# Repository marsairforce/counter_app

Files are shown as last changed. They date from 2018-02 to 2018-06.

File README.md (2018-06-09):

# A simple counter application

This is a device that has 2 7-segment displays, and buttons.
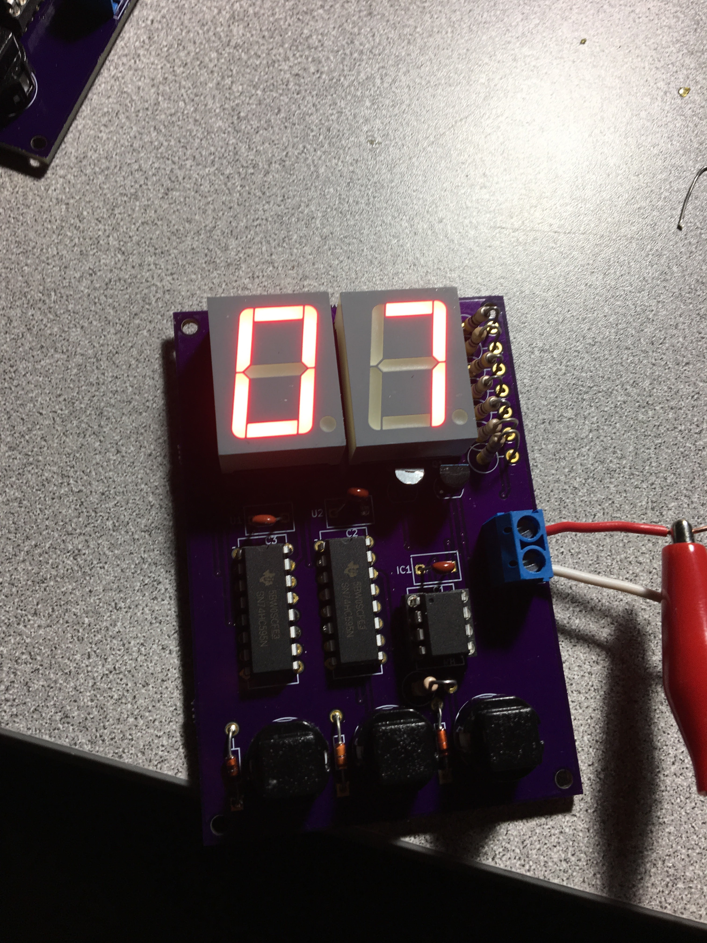
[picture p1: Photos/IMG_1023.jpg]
Counter Application


It can be used for simple manual counting of something.
I originally built it for a "It has been xx days since.." signs.

But it can also be used for one of those "Now serving xx" signs.

This project was a test of the waters to see what OSHPark is able to create.

It started off as a breadboard experiment, then a hand wire job on a punchboard, and then a finished PCB board.

It was an exercise to learn how to use Kicad as well. Before I had been trying to use gEDA and suite to make a circuit board layout, but never got past the schematic phase. Perhaps because there is no existing parts or footprint library for gEDA and also no documentation for how to use the tools (that are not even GUI based) to try to create a symbol and a footprint.  I was able to get farther with Kicad in an evening than I was able to get over several years of coming back to poking at gEDA.

It was also the first product built using Attiny-85 device. Learning how to use shift registers, multiplex switch button inputs, software interrupts.

All the components were things I had in stock, thru-hole parts.

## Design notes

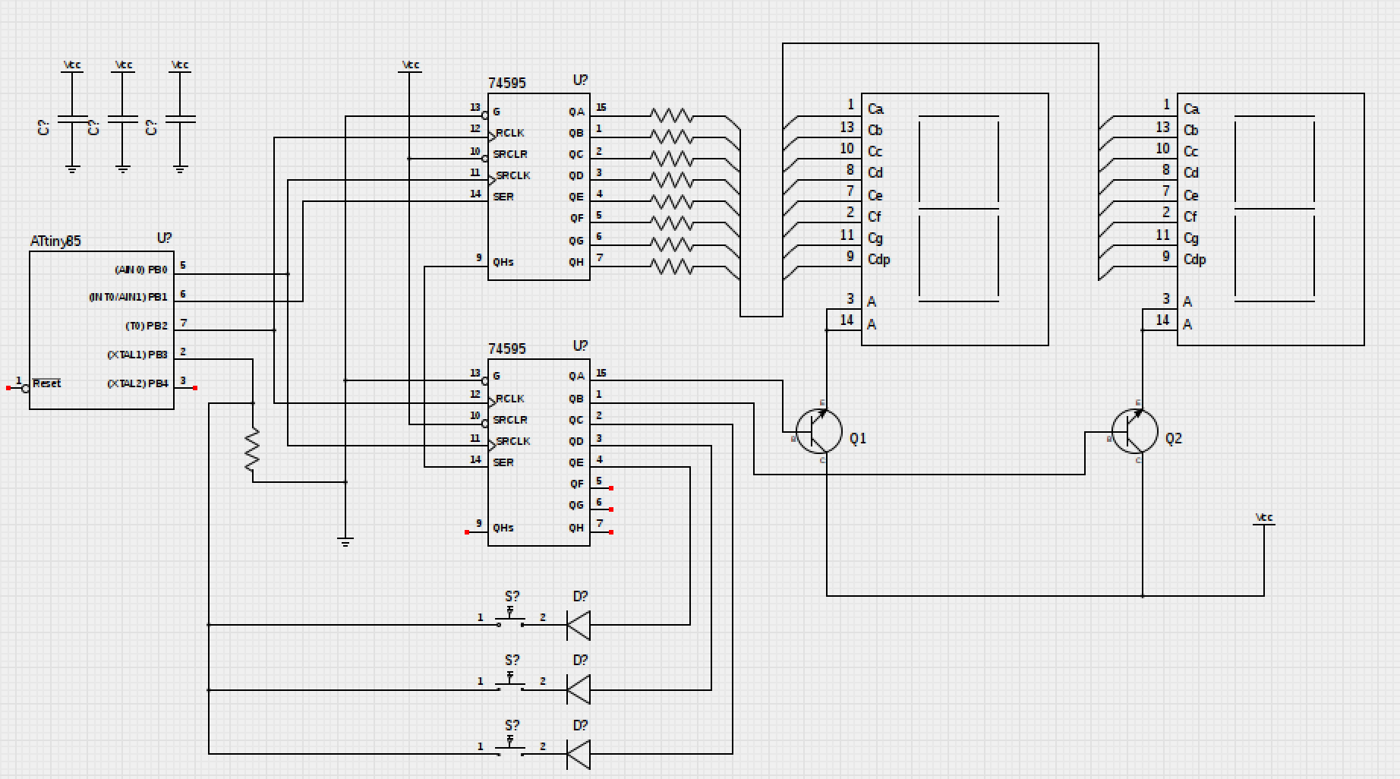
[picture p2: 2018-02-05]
Photos/Screen Shot 2017-01-28 at 11.42.11 PM.png

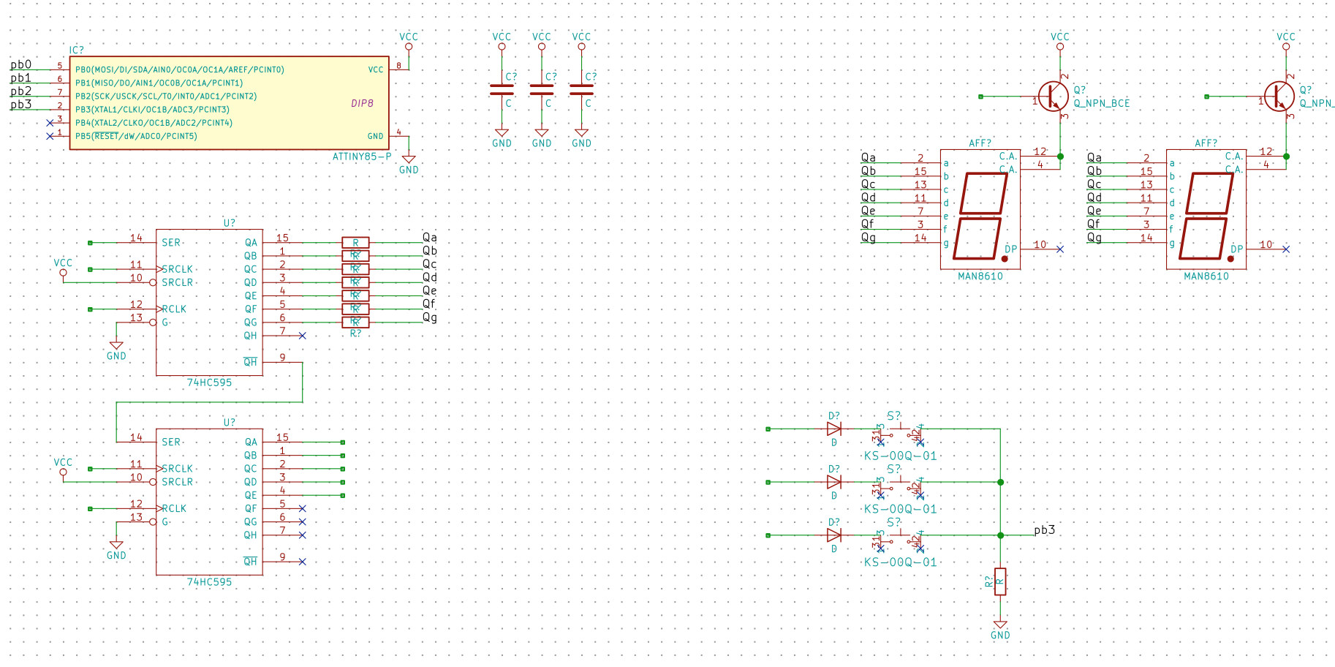
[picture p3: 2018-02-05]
Photos/Screen Shot 2017-01-30 at 12.58.02 AM.png

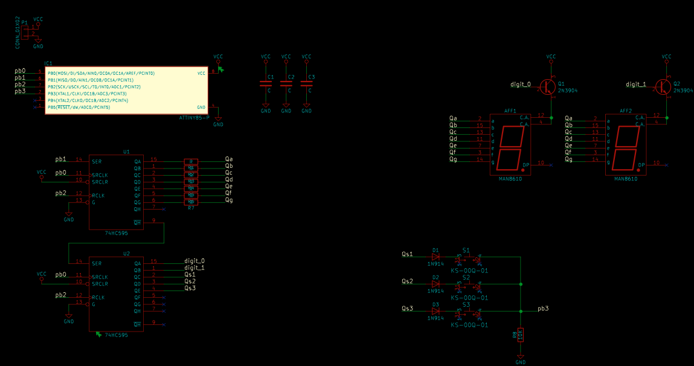
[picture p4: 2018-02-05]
Photos/Screen Shot 2017-02-01 at 12.23.13 AM.png

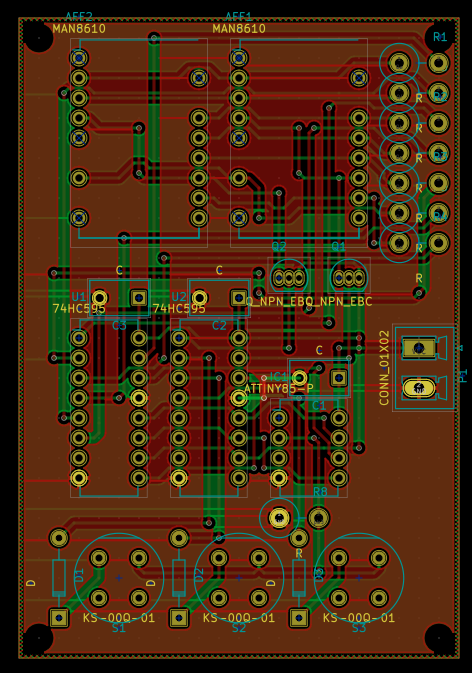
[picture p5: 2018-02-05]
Photos/Screen Shot 2017-02-01 at 12.17.23 AM.png

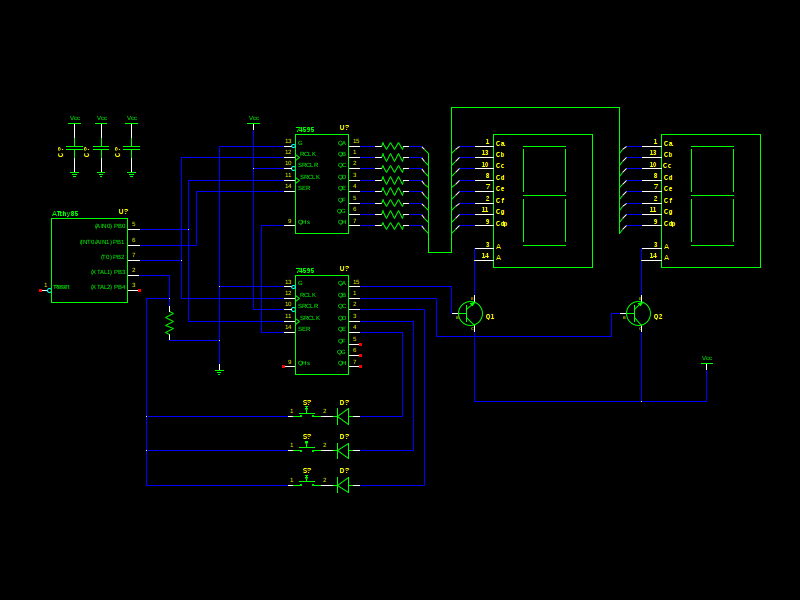
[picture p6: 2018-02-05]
sketch_jan25a.png

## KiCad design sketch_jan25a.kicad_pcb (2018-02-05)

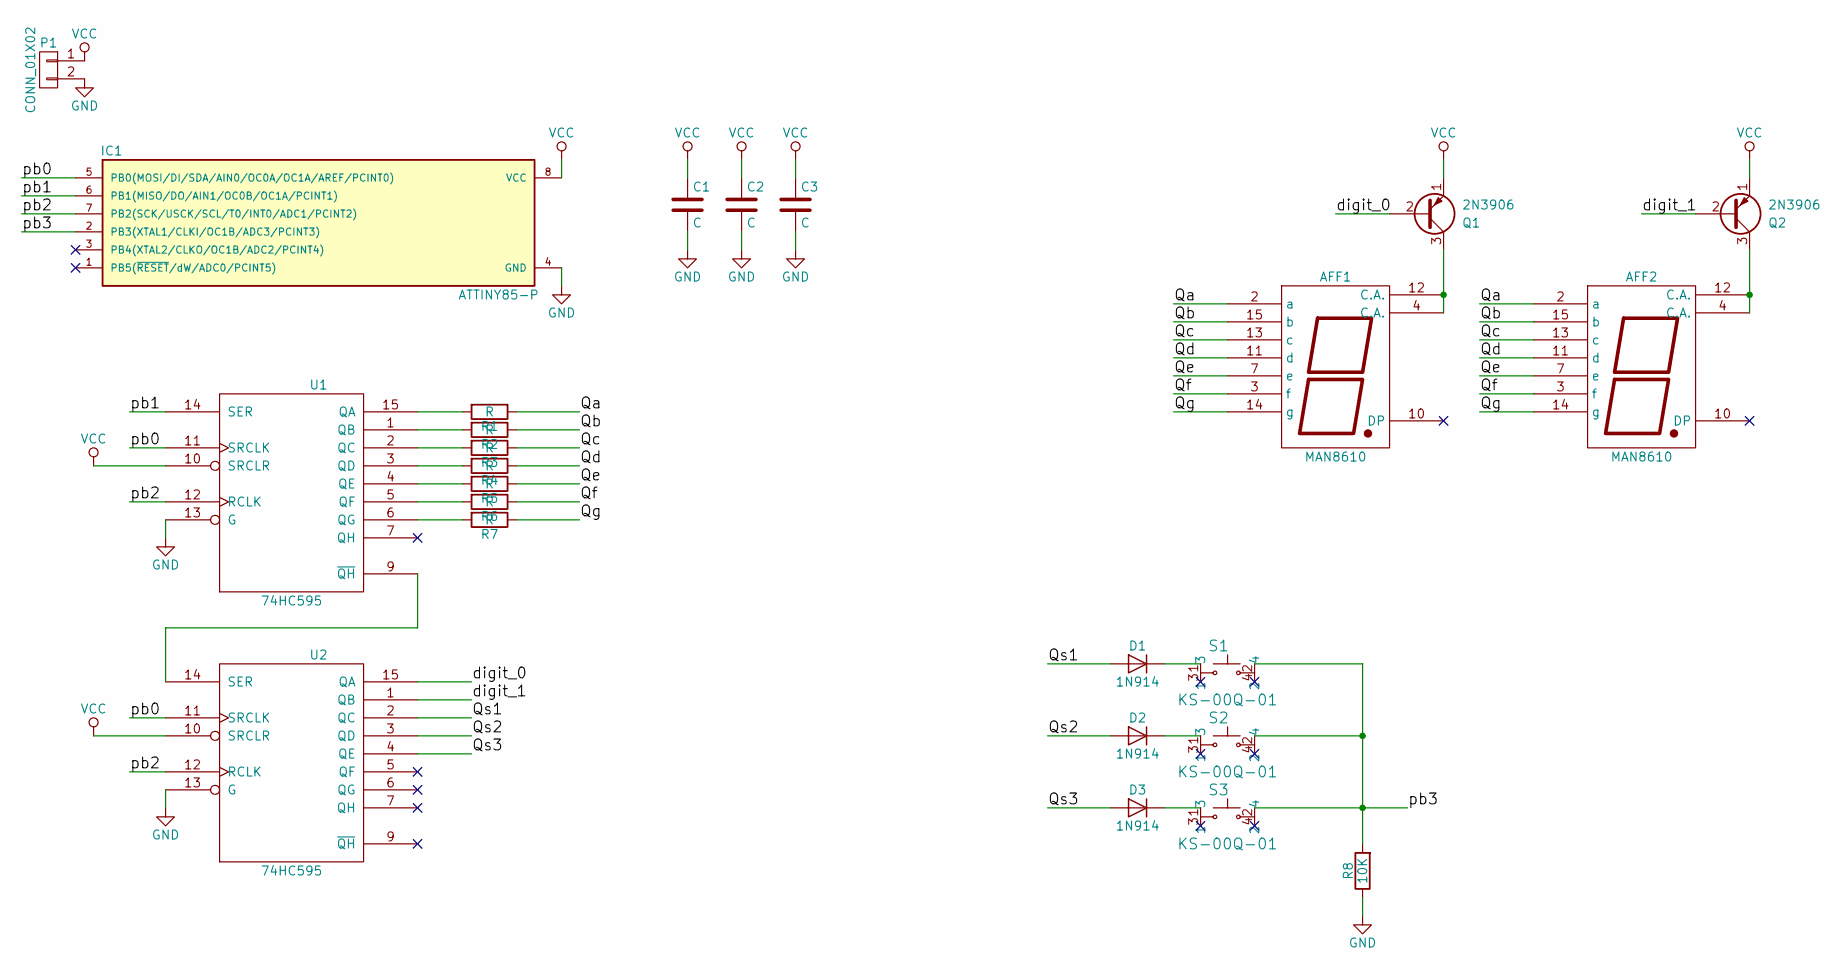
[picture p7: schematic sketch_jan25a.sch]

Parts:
AFF1, AFF2: MAN8610
C1, C2, C3: C; C_Rect_L7_W2.5_P5
D1, D2, D3: 1N914; Diode_DO-35_SOD27_Horizontal_RM10
IC1: ATTINY85-P; DIP-8_W7.62mm
P1: CONN_01X02
Q1, Q2: 2N3906; TO-92_Inline_Narrow_Oval
R1, R2, R3, R4, R5, R6, R7: R; Resistor_Vertical_RM5mm
R8: 10K; Resistor_Vertical_RM5mm
S1, S2, S3: KS-00Q-01; e_switch
U1, U2: 74HC595; DIP-16_W7.62mm

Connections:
/Qa: AFF1.2 (a), AFF2.2 (a), R1.1
/Qb: AFF1.15 (b), AFF2.15 (b), R2.1
/Qc: AFF1.13 (c), AFF2.13 (c), R3.1
/Qd: AFF1.11 (d), AFF2.11 (d), R4.1
/Qe: AFF1.7 (e), AFF2.7 (e), R5.1
/Qf: AFF1.3 (f), AFF2.3 (f), R6.1
/Qg: AFF1.14 (g), AFF2.14 (g), R7.1
/Qs1: D1.2 (A), U2.2 (QC)
/Qs2: D2.2 (A), U2.3 (QD)
/Qs3: D3.2 (A), U2.4 (QE)
/digit_0: Q1.2 (B), U2.15 (QA)
/digit_1: Q2.2 (B), U2.1 (QB)
/pb0: IC1.5 (PB0(MOSI/DI/SDA/AIN0/OC0A/OC1A/AREF/PCI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), U1.11 (SRCLK), U2.11 (SRCLK)
/pb1: IC1.6 (PB1(MISO/DO/AIN1/OC0B/OC1A/PCINT1)), U1.14 (SER)
/pb2: IC1.7 (PB2(SCK/USCK/SCL/T0/INT0/ADC1/PCINT2)), U1.12 (RCLK), U2.12 (RCLK)
/pb3: IC1.2 (PB3(XTAL1/CLKI/OC1B/ADC3/PCINT3)), R8.2, S1.2, S2.2, S3.2
GND: C1.2, C2.2, C3.2, IC1.4 (GND), P1.2, R8.1, U1.8 (GND), U1.13 (G), U2.8 (GND), U2.13 (G)
unnamed: AFF1.4 (C.A.), AFF1.12 (C.A.), Q1.3 (C)
unnamed: AFF2.4 (C.A.), AFF2.12 (C.A.), Q2.3 (C)
unnamed: D1.1 (K), S1.1
unnamed: D2.1 (K), S2.1
unnamed: D3.1 (K), S3.1
unnamed: R1.2, U1.15 (QA)
unnamed: R2.2, U1.1 (QB)
unnamed: R3.2, U1.2 (QC)
unnamed: R4.2, U1.3 (QD)
unnamed: R5.2, U1.4 (QE)
unnamed: R6.2, U1.5 (QF)
unnamed: R7.2, U1.6 (QG)
unnamed: U1.9 (~QH), U2.14 (SER)
VCC: C1.1, C2.1, C3.1, IC1.8 (VCC), P1.1, Q1.1 (E), Q2.1 (E), U1.10 (SRCLR), U1.16 (VCC), U2.10 (SRCLR), U2.16 (VCC)

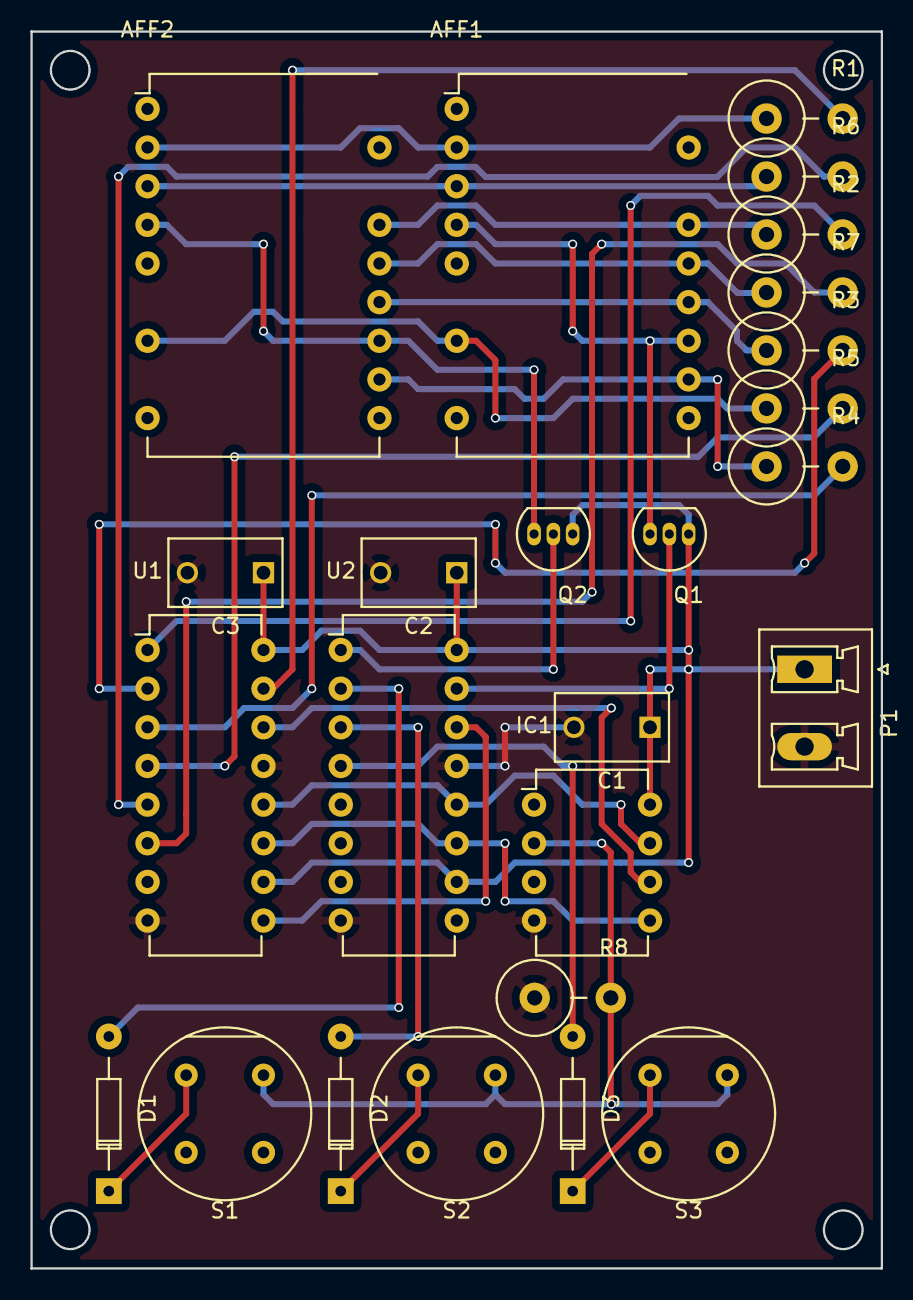
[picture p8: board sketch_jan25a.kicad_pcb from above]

Board: 2 copper layers, 55.9 x 81.3 mm, 25 parts (0 on the bottom side), 31 nets.

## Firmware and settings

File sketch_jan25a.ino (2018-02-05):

/*
 * The "It has ben XX days since .. Application.
 * 
 * Two displays. Three buttons. To control the value displayed.
 * 
 * Where we drive the cathodes with one 74595 and the anodes (through a transistor driver) with another 74595.
 * Using the extra pins on the 2nd 74595 to drive up to 6 switch inputs.
 * 
 * Trying to get this onto ATtiny85
 * 
 * PB2 (7) - RCLK (12)
 * PB1 (6) - SER (14)
 * PB0 (5) - SRCLK (11)
 * PB3 (2) - switch input
 * 
 * Where the 74595(1) is connected to the 7 segment display as
 * Q0 - Ca
 * Q1 - Cb
 * Q2 - Cc
 * Q3 - Cd
 * Q4 - Ce
 * Q5 - Cf
 * Q6 - Cg
 * Q7 - Cdp
 * 
 * And the 74595(2) is connected to the transistor drivers.
 * Q0 - 1's digit
 * Q1 - 10's digit
 * Q2 - S0 - reset
 * Q3 - S1 - increment
 */

// these are bit positions for shifting, instead of using digital write
// so we can do PORTB |= (1<<pin) to set
// and PORTB &= ~(1<<pin) to clear
// Since this saves us 4 microseconds per operation.

#define sbi(port,bit) \
  (port) |= (1 << (bit)) 

#define cbi(port,bit) \
  (port) &= ~(1 << (bit)) 
  
#include <avr/interrupt.h>

const int clockPin = 0; // PB0 connected to SRCLK on 74595
const int dataPin = 1; // PB1 connected to SER on 74595
const int latchPin = 2; // conected to RCLK on 74595
const int inputPin = 3; // connected to pushbutton switches after 2nd 74595
// 4
// 5 - requires a high voltage programmer to reprogram device is we remove reset function?

// display 0,1,2,3,4,5,6,7,8,9, MSB shifted first (LSB is a segment)
int datArray[10] = { 0xC0, 0xF9, 0xA4, 0xB0, 0x99, 0x92, 0x82, 0xF8, 0x80, 0x90 };
// LSB shifted first
//int datArray[10]= { 0x03, 0x9F, 0x25, 0x0D, 0x99, 0x49, 0x41, 0x1F, 0x01, 0x09 };

const int maxDigits = 2;

// the digit to display
int digitMap[maxDigits] = { 0x02, 0x01 }; // pnp transistors, so these are active low now.

// we basically use unpacked BCD
// [0] - one's digit
// [1] - ten's digit
int displayValue[maxDigits];


// causes one digit to be written to the 7 segment display
// value: the index to the digitArray to display.
// digit: a value from 0-7
void writeDigit(int value, int digit) {
  
    PORTB &= ~(1<<latchPin);// ground latch pin and hold low as long as we are transmitting data.

    // the switches are "after" the display driver, so the need to be shifted first.
    // practically we combine the switch bitmap with the active display digit map, writing a 1 to the enabled switches
    // which is currently the lower 6 bits. 0x2F
    int  control = digitMap[digit]|0xFC;
    // because we have the anode and transistor driver wired after the cathode driver, we have to shift it out first.
    shiftOut(dataPin, clockPin, MSBFIRST, control);

    
    // we used to need to drive out LSB first, because we have Q0 connected to Ca, which is last
    // but reversed our bitmap abover to support MSB first. Either that or we could rewire the display.
    shiftOut(dataPin, clockPin, MSBFIRST, datArray[value]);  
    
    //digitalWrite(latchPin, HIGH);
    PORTB |= (1<<latchPin);
}

void resetDigits() {
  for (int i = 0; i < maxDigits; i++) {
    displayValue[i] = 0;
  }
}

volatile boolean checking_input = false;

void writeDigits() {
  if (checking_input) {
    // do not try to update display if we are trying to read an input.
    return;
  }
  for (int n = 0; n < maxDigits; n++) {
  
    writeDigit(displayValue[n], n);
   // delay(4);
  }
}

void increment() {
  for (int i = 0; i < maxDigits; i++) {
    displayValue[i] ++;
    if (displayValue[i] > 9) {
      displayValue[i] = 0;
      if (i + 1 < maxDigits) {
        continue;
      }
    }
    else {
      break;
    }
  } // for
}

void decrement() {
  int borrow = false;
  // do the ten's compliment of each digit
  for (int i = 0; i < maxDigits; i++) {
    int compliment=0;
    if (borrow) {
      10-displayValue[i];
    }
    else {
      compliment=10-1;
    }
    int result = (displayValue[i] + compliment);
    if (result >=10) {
      borrow = true;
    }
    displayValue[i] = result % 10;
  } // for
}

void setup() {     
  
  // put your setup code here, to run once:
  pinMode(latchPin, OUTPUT);
  pinMode(clockPin, OUTPUT);
  pinMode(dataPin, OUTPUT);
  pinMode(inputPin, INPUT);
  
  resetDigits();

  cli();
  GIMSK |= (1 << PCIE); // enable pin change interrupts
  //sbi(PCMSK, PCINT3);
  PCMSK |= (1 << PCINT3);
  sei();

}

// inspired by Arduino inputs from 74595 http://www.kevindarrah.com/download/arduino_code/ShiftRegisterInput2_piano.ino
//void pin_read(){
ISR(PCINT0_vect) {

  if (GIFR & (1 << PCIF) == 0) {
    return; // not a pin change interrupt
  }
    // switch debouncing logic
    for(int j=0; j<50; j++) {
      delayMicroseconds(1000);
    }
    
    if (digitalRead(inputPin) == LOW) {
      return;
    }

  checking_input = true;
   
    // determine which button(s) are presesed
    // shift out the bitmap that represents the 1st button
    PORTB &= ~(1<<latchPin);
    shiftOut(dataPin, clockPin, MSBFIRST, 0x07); // 0x04 for the switch, + 0x03 to cause displays to blank.
    shiftOut(dataPin, clockPin, MSBFIRST, 0x00);
    PORTB |= (1<<latchPin);
    if (digitalRead(inputPin) == HIGH) {
      resetDigits();
      goto done;
    }

    // shift out the bitmap that represents the 2nd button
    PORTB &= ~(1<<latchPin);
    shiftOut(dataPin, clockPin, MSBFIRST, 0x0B); // 0x08 for the switch, + 0x03 to cause displays to blank.
    shiftOut(dataPin, clockPin, MSBFIRST, 0x00);
    PORTB |= (1<<latchPin);
    if (digitalRead(inputPin) == HIGH) {
      decrement();
      goto done;
    }

    // shift out the bitmap that represents the 3rd button
    PORTB &= ~(1<<latchPin);
    shiftOut(dataPin, clockPin, MSBFIRST, 0x13); // 0x10 for the switch, + 0x03 to cause displays to blank.
    shiftOut(dataPin, clockPin, MSBFIRST, 0x00);
    PORTB |= (1<<latchPin);
    if (digitalRead(inputPin) == HIGH) {
      increment();
      goto done;
    }


done:
    // keep us here until button is released.
    while(digitalRead(inputPin) == HIGH){ 
      delayMicroseconds(1000); 
    }

  checking_input = false;
}//pin_read


void loop() {
  writeDigits();
}
